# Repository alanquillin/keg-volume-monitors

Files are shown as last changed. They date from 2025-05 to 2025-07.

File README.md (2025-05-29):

# DIY Keg Volume Monitors

While there are many commercially available monitors for kegs out there, this project is designed for the DIY/tinkerer at heart and aimed to be a more cost effective way to add volume monitors to your kegs.  The core of these monitors is the particle.io Photon 2 micro-controller.  This low cost micro-controller adds Wifi and BluetoothLE support as well and integrated cloud.  This allows the keg monitor service to get stats and execute functions against the devices even when they are not on the same network. The particle.io cloud is free (for up to 100 devices) so it makes it perfect for this type of DIY project.  While there are cheaper micro-controllers out there, the Photon 2 was chosen because its extra features were worth the extra few dollars.

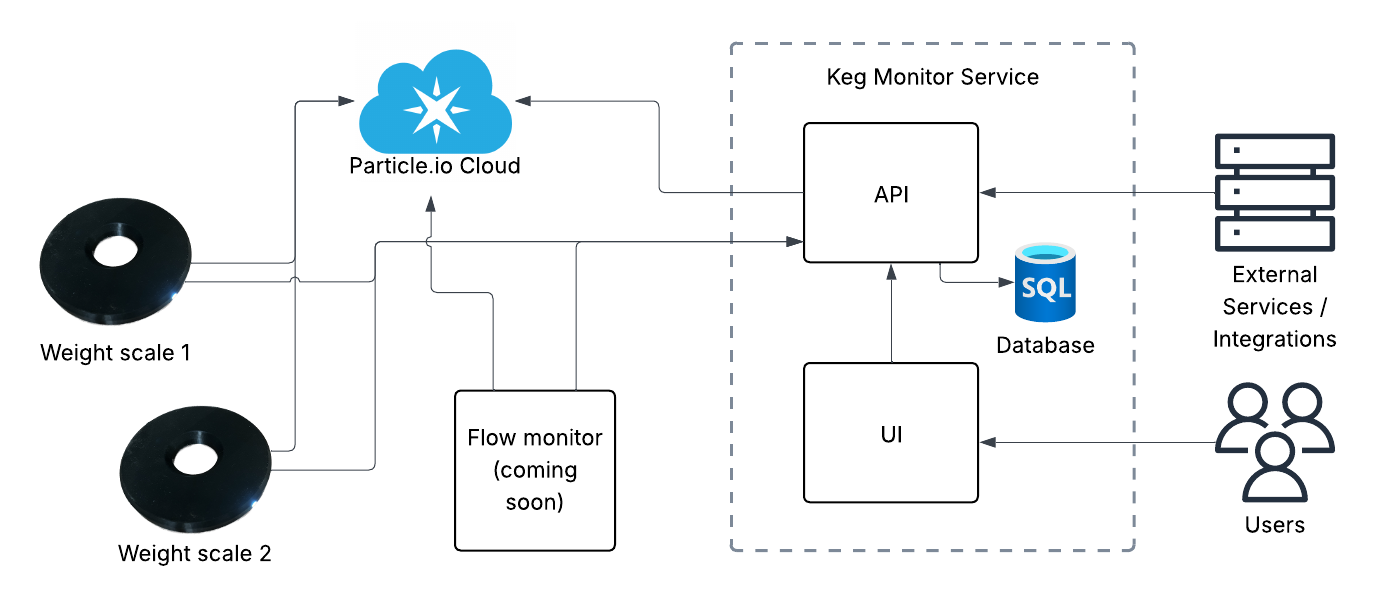
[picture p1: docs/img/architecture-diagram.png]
Weight scale monitor pic


## Monitors

- [Weight Scale](./monitors/weight/README.md): Monitors the volume of the keg based on the current weight.
- Flow Monitor _(coming soon)_: Monitors the remaining volume in the keg bacged on how much liquid flowed through the sensors.

## The web service

The core of all of this is the web service.  This offers an API, both for the devices to post too, as well as external services to integrate with.  There is also a light weight UI for viewing the status of and managing the devices.  The service also proxies the calls to particle cloud to execute certain functions on the different devices.

## Whats next?

See our [issues page](https://github.com/alanquillin/keg-volume-monitors/issues) for upcoming milestones and changes on our roadmap.

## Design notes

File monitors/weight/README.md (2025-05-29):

# Weight Based Keg Volume Monitor

Inspired by the now discontinued Plaato keg, this monitor uses the weight of the keg over time to determine the current
 volume based on the weight of the empty keg and the weight of a full keg.  I love the Plaato keg, and was sad when they
 announced their pivot away from home brewing gear and would no longer be selling, innovating or supporting the Plaato
 keg.  In my search I found a few other DIY clones using low cost hardware and existing technologies.  However, I wanted
 to build some truly DIY with fully opensource software.  So I designed my own keg scale using the Particle Photon 2 platform.

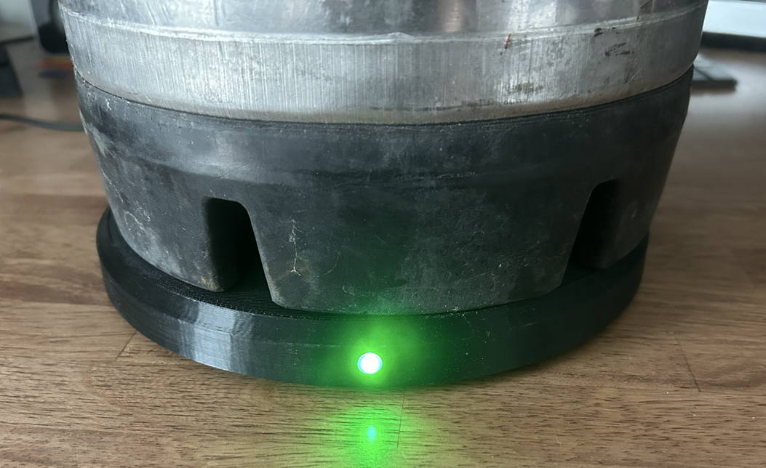
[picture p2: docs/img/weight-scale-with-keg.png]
Weight scale monitor pic

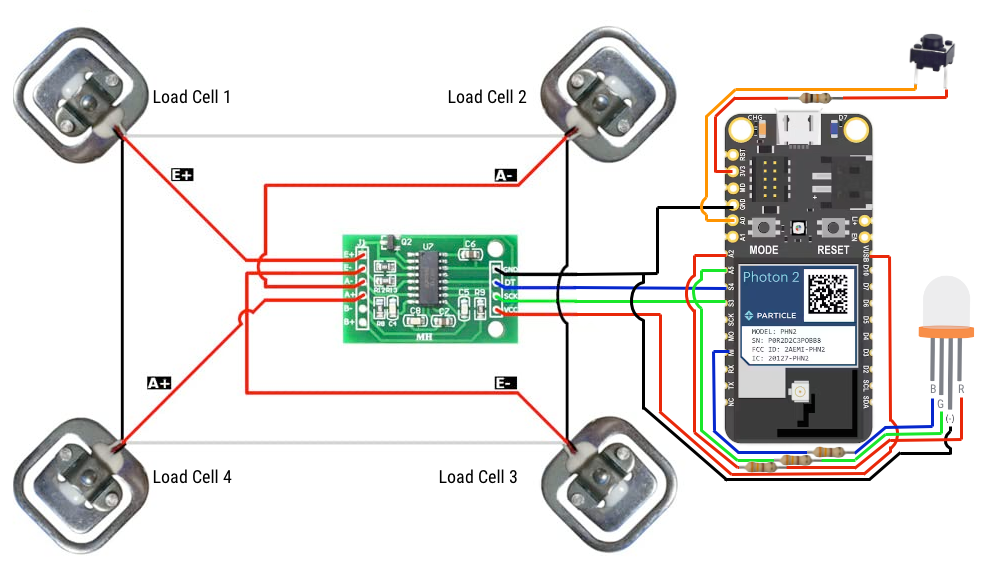
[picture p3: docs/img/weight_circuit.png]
Weight scale monitor - load cell circuit diagram


## Parts required

- [Particle Photon2](https://store.particle.io/products/photon-2) (optionally will work with discontinued Photon or Argon)
- [4 Load Cells w/ HX711 amplifier](https://www.amazon.com/Bridge-Digital-Amplifier-Arduino-DIYmalls/dp/B086ZHXNJH)
- [5mm RGB Led (common cathode)](https://www.amazon.com/PATIKIL-Emitting-Mounting-Bracket-Transparent/)
- 3X 330 ohm Resistor
- [5mm LED holder](https://www.amazon.com/PATIKIL-Emitting-Mounting-Bracket-Transparent/dp/B0C54Y99NQ)

### Optional components

- Micro USB cable (is using the optinal riser boards below, I would recommend a cable with extremely slim connectors
like [these](https://www.amazon.com/dp/B09XKYP32W).  The .stl files for the case add additional room for the cables, but its better to be safe than sorry ;P)
- [6mmX6mm single pole push button switch](https://www.amazon.com/dp/B07WF76VHT)
- 10k Ohm resistor

#### Optional Parts for custom riser boards

I have added the [EAGLE files](./eagle) to manufacture helper riser boards simplify and cleanup the internal wiring.  Please [contact me](mailto:alanquillin@gmail.com) for more information. 

- JST-PH connectors
  - 4 pole connectors
    - 3 X [S4B-PH-K-S](https://www.digikey.com/en/products/detail/jst-sales-america-inc/S4B-PH-K-S/926628) right angle female through hole solder connectors
    - 1 X [B4B-PH-K-S](https://www.digikey.com/en/products/detail/jst-sales-america-inc/B4B-PH-K-S/926613) straight female through hole solder connector
    - 8 X [PHR-4](https://www.digikey.com/en/products/detail/jst-sales-america-inc/PHR-4/608606) male connectors
  - 3 pole
    - 4 X [S3B-PH-K-S](https://www.digikey.com/en/products/detail/jst-sales-america-inc/S3B-PH-K-S/926627) female through hole solder connectors
    - 8 X [PHR-3](https://www.digikey.com/en/products/detail/jst-sales-america-inc/PHR-3/527357) male connectors
  - 2 pole
    - 2 X [S2B-PH-K-S](https://www.digikey.com/en/products/detail/jst-sales-america-inc/S2B-PH-K-S/926626) female through hole solder connectors
    - 4 X [PHR-2](https://www.digikey.com/en/products/detail/jst-sales-america-inc/PHR-2/608607) male connectors
  - 20 X [SPH-004](https://www.digikey.com/en/products/detail/jst-sales-america-inc/SPH-004T-P0-5S/608759) crimp terminal pins
- [2m X 6MM self taping screws](https://www.amazon.com/dp/B01KXS7TOI).  The STLs do not have pre-drilled holed for the screws to hold the circuit boards, and thats because the risers are not perfect ;P, so self taping screws will allow you to screw right into the solid plastic.

## Links

- [Another DIY Plaato Keg clone](https://www.youtube.com/watch?v=QF1B8yD9jy4) from the [Trouble Brewing](https://www.youtube.com/@TroubleBrewing)
YouTube channel.  This one uses a NodeMCU 8266 module and Home Assistant Server.  However, I am not a huge fan of these modules or Home Assistant
and I wanted to build something with fully opensource software.
- [Wiring up and calibrating HX711 with 4 load cell using arduino](https://www.youtube.com/watch?v=LIuf2egMioA)

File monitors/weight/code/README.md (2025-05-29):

# Weight Based Keg Volume Monitor: Controller Firmware

## Setting up wifi

To initiate or update the WiFi for a given device, make sure to add your wifi redencials to the local `wifi-creds.json`.  

``` json
{
    "network": "MYSSID",
    "security": "WPA2_PSK",
    "password": "MYWIFIPASS",
    "hidden": false
}
```

for more details see the [documentation](https://docs.particle.io/reference/developer-tools/cli/).

Then update the device with following command

``` shell
make initi-wifi
```

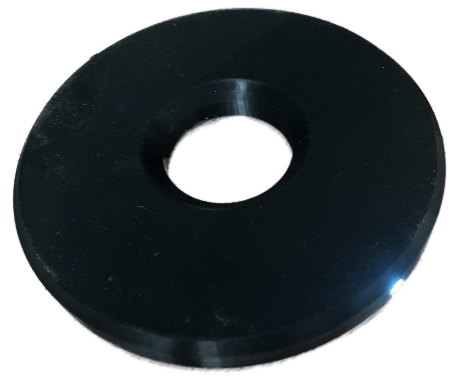
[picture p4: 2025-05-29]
docs/img/weight-scale-transparent.png

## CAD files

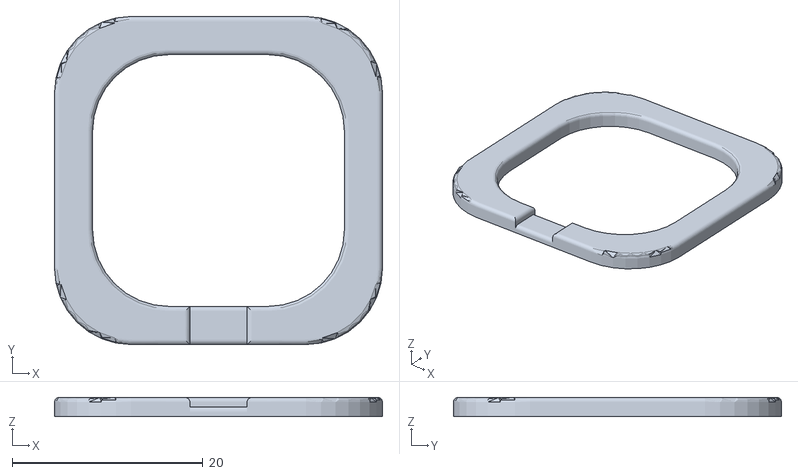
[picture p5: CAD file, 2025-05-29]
monitors/weight/stl/Keg Weight Monitor - Load Cell Mount Top Bevel.stl
34.4 x 34.4 x 2.00

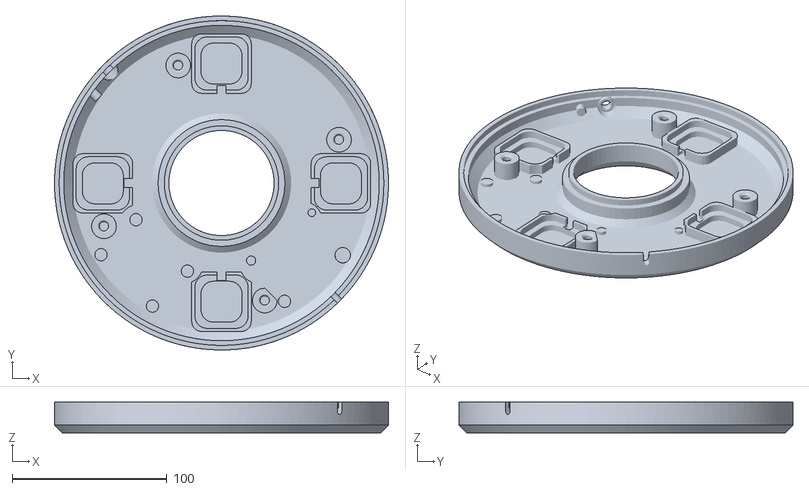
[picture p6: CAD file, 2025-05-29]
monitors/weight/stl/Keg Weight Monitor - Top.stl
216.0 x 216.0 x 20.0

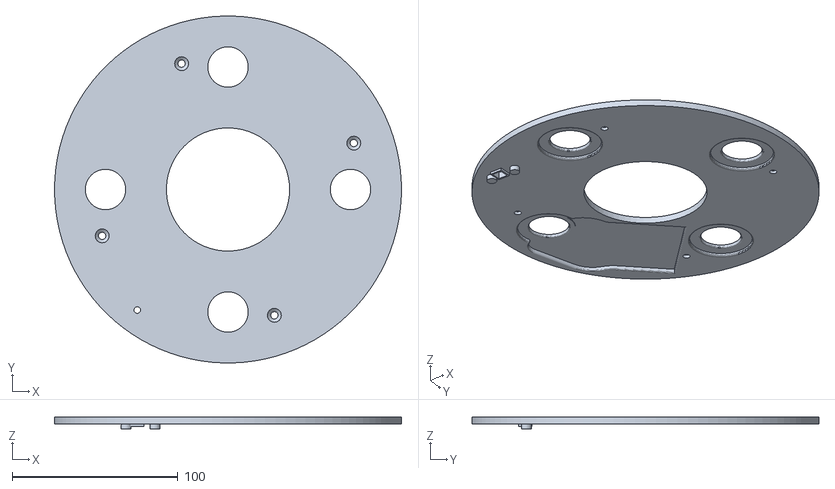
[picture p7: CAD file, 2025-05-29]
monitors/weight/stl/Keg Weight Monitor - Bottom.stl
209.6 x 209.5 x 7.00

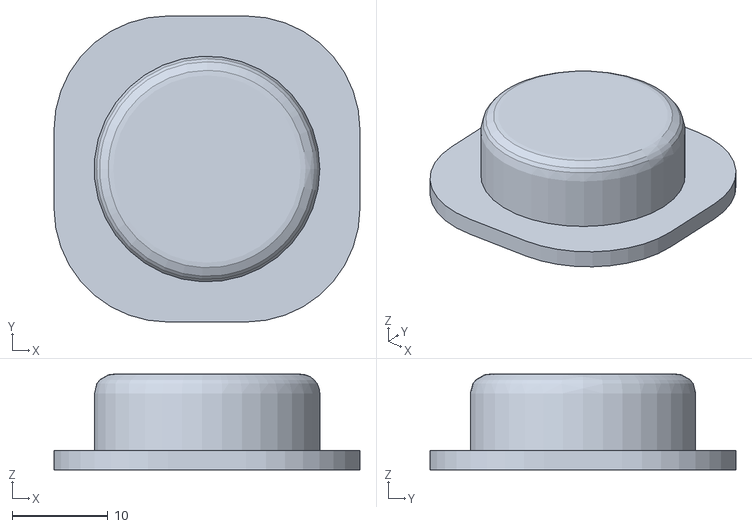
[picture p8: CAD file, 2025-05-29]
monitors/weight/stl/Keg Weight Monitor - Feet.stl
32.0 x 32.0 x 10.0

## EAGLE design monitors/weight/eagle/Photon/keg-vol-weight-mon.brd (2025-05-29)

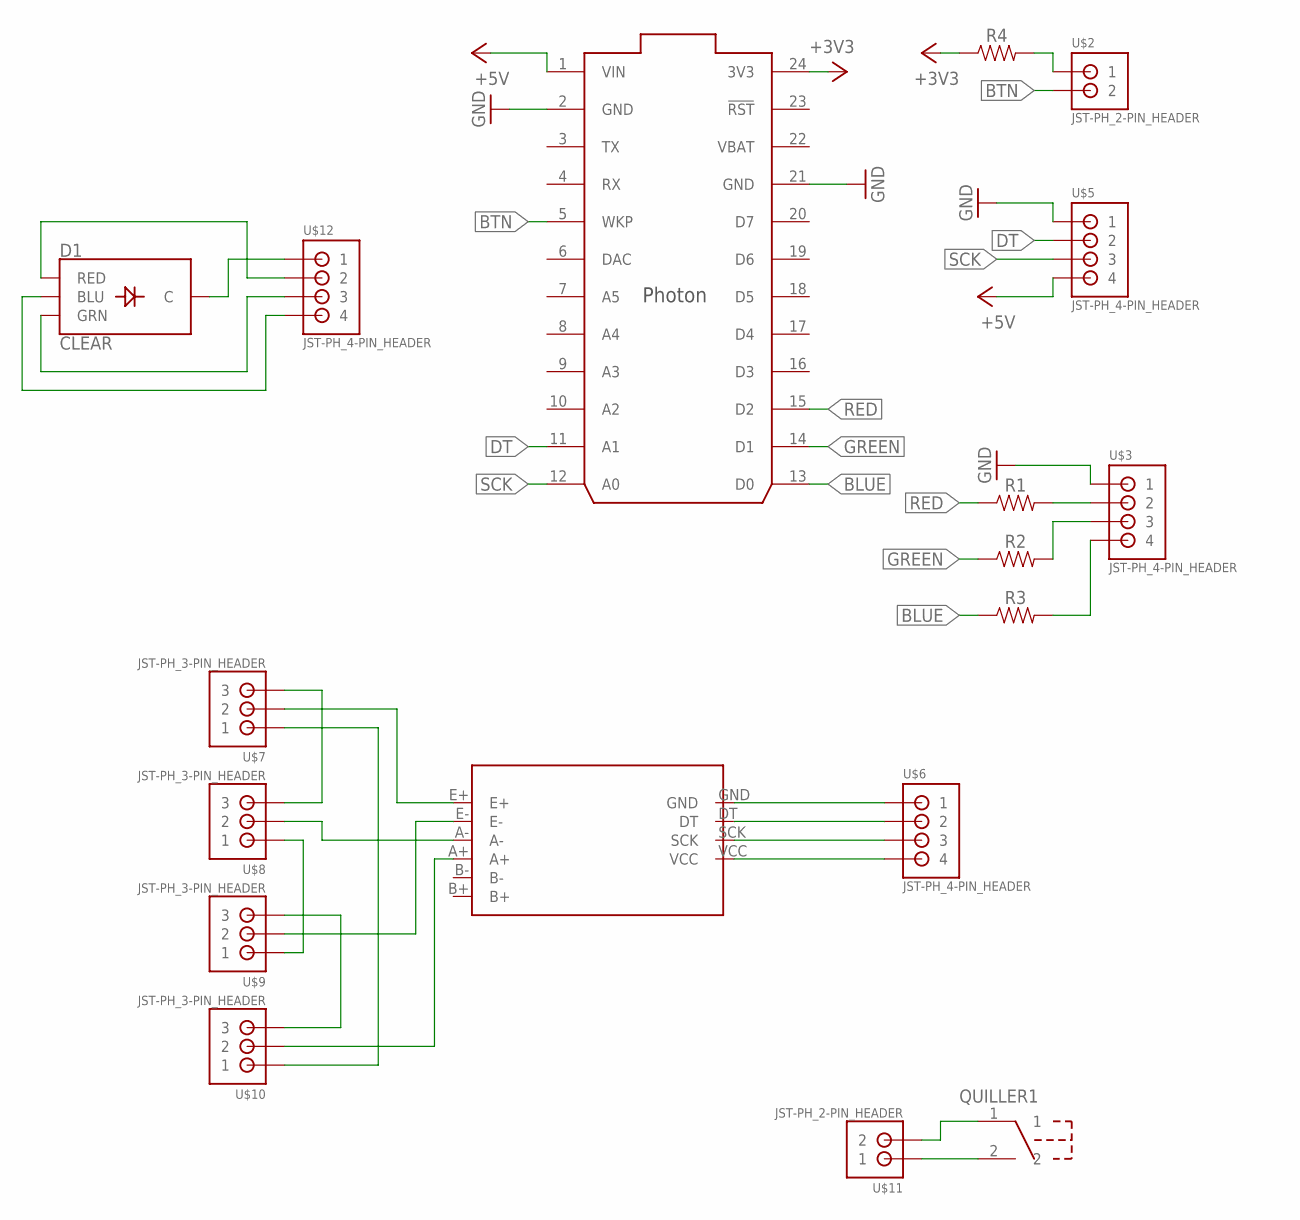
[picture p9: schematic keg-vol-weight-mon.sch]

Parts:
D1: CLEAR; LED-RGB-THRU
QUILLER1: 6MM-2PIN-TAC-MOM-SWITCH
R1, R2, R3, R4: AXIAL-0.3
U$1: PHOTON_WITH_HEADERS; PHOTON
U$2, U$11: JST-PH_2-PIN_HEADER; JST_B2B-PH_HEADER
U$3, U$5, U$6, U$12: JST-PH_4-PIN_HEADER; JST_B4B-PH_HEADER
U$4: HX711
U$7, U$8, U$9, U$10: JST-PH_3-PIN_HEADER; JST_B3B-PH_HEADER

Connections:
+3V3: R4.P$1 (1), U$1.24 (3V3)
+5V: U$1.1 (VIN), U$5.P4 (4)
BLUE: R3.P$1 (1), U$1.13 (D0)
BTN: U$1.5 (WKP), U$2.P2 (2)
DT: U$1.11 (A1), U$5.P2 (2)
GND: U$1.2 (GND), U$1.21 (GND), U$3.P1 (1), U$5.P1 (1)
GREEN: R2.P$1 (1), U$1.14 (D1)
unnamed: R2.P$2 (2), U$3.P3 (3)
unnamed: R3.P$2 (2), U$3.P4 (4)
unnamed: R4.P$2 (2), U$2.P1 (1)
unnamed: U$4.E+, U$7.P2 (2)
unnamed: R1.P$2 (2), U$3.P2 (2)
unnamed: U$4.A-, U$8.P2 (2)
unnamed: U$4.E-, U$9.P2 (2)
unnamed: U$4.A+, U$10.P2 (2)
unnamed: U$7.P3 (3), U$8.P3 (3)
unnamed: U$8.P1 (1), U$9.P1 (1)
unnamed: U$9.P3 (3), U$10.P3 (3)
unnamed: U$7.P1 (1), U$10.P1 (1)
unnamed: U$4.GND, U$6.P1 (1)
unnamed: U$4.DT, U$6.P2 (2)
unnamed: U$4.SCK, U$6.P3 (3)
unnamed: U$4.VCC, U$6.P4 (4)
unnamed: QUILLER1.1, U$11.P2 (2)
unnamed: QUILLER1.2, U$11.P1 (1)
unnamed: D1.2 (C), U$12.P1 (1)
unnamed: D1.4 (BLU), U$12.P4 (4)
unnamed: D1.3 (GRN), U$12.P3 (3)
unnamed: D1.1 (RED), U$12.P2 (2)
RED: R1.P$1 (1), U$1.15 (D2)
SCK: U$1.12 (A0), U$5.P3 (3)
VBAT: U$1.22 (VBAT)

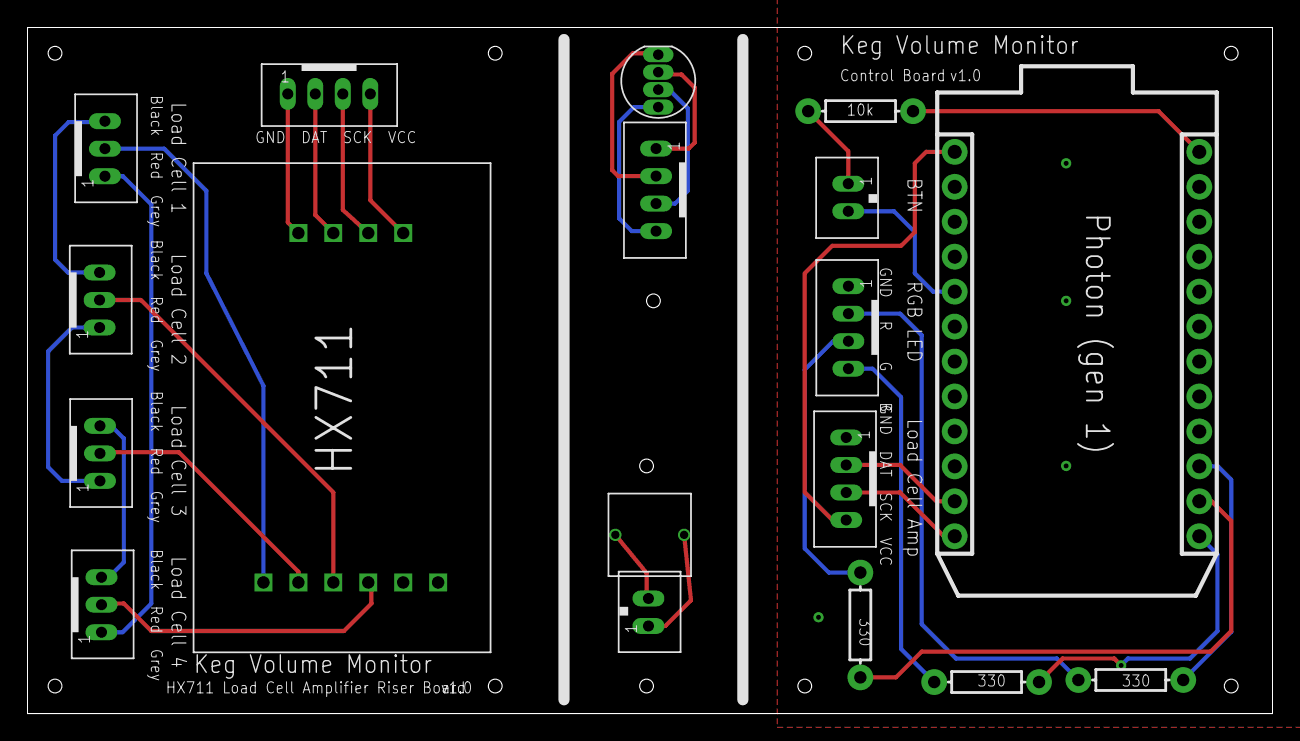
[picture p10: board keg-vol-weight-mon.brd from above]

Board: 2 copper layers, 90.5 x 49.9 mm, 18 parts (0 on the bottom side), 31 nets.

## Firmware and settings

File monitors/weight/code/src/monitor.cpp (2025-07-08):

#include "Particle.h"
#include "env.h"
#include "config.h"
#include <HX711ADC.h>
#include <math.h>
//#include "../../../shared-lib/rgb_led.h"
#include "rgb_led.h"
//#include "../../../shared-lib/service.h"
#include "service.h"

SYSTEM_MODE(SEMI_AUTOMATIC);
// Run Setup code immediately.  This is enabled by default in OS v6.2.0 and above
#if (SYSTEM_VERSION < SYSTEM_VERSION_DEFAULT(6, 2, 0))
SYSTEM_THREAD(ENABLED);
#endif

// declare function prototypes
bool sendStatus();
bool getSetDeviceData();

Timer statusUpdater(STATUS_UPDATE_PERIOD_MS, sendStatus);

SerialLogHandler logHandler(LOG_LEVEL_WARN, {
    { "app", LOG_LEVEL_TRACE }, // Default logging level for all app messages
    { "app.service", LOG_LEVEL_TRACE } // Logging level for data service
});

HX711ADC scale(HX711_DOUT_PIN, HX711_SCK_PIN);		// parameter "gain" is omitted; the default value 128 is used by the library
RGBLED led(RED_PIN, GREEN_PIN, BLUE_PIN);
DataService dataService(SERVICE_ENABLED, "weight", HOSTNAME, PORT, API_KEY, false);
device_data_t deviceData = {true};

float EMPTY_KEG_W = DEFAULT_EMPTY_KEG_W;
float LAST_MEASUREMENT = 0;
time32_t LAST_MEASUREMENT_TS = 0;

bool BTN_PRESSED = false;
unsigned long BTN_PRESSED_ON;
bool CALIBRATION_MODE_ENABLED = false;
bool CALIBRATING = false;
bool TESTING_LEDS = false;
bool MAINTENANCE_MODE = false;

int _getState(bool doPing) {
    if (CALIBRATING) {
        return 11;
    }

    if (CALIBRATION_MODE_ENABLED) {
        return 10;
    }

    if (MAINTENANCE_MODE) {
        return 99;
    }

    if (doPing) {
        if (!dataService.ping()) {
            return 2;
        }
    }

    return 1;
}

void storeCalibrationScale(float cal) {
    EEPROM.put(0, cal);
}

float getCalibrationScale() {
    float cal;
    EEPROM.get(0, cal);
    return cal;
}

void storeCalibrationOffset(long offset) {
    EEPROM.put(4, offset);
}

long getCalibrationOffset() {
    long offset;
    EEPROM.get(4, offset);
    return offset;
}

void storeEmptyKegWeight(float val) {
    EEPROM.put(8, val);
}

float getEmptyKegWeight() {
    float val;
    EEPROM.get(8, val);
    return val;
}

bool sendStatus() {
    if (deviceData.isNull) {
        Log.trace("No device info currently set, attempting to retrieve before sending status");
        if(!getSetDeviceData()){
            Log.warn("No device info found from service.  Service may not be available ATM, skipping sendStatus.");
            return false;
        }
    }

    device_status_t status;
    status.id = deviceData.id;
    status.latestMeasurement = LAST_MEASUREMENT;
    status.latestMeasurementTS = LAST_MEASUREMENT_TS;
    status.emptyKegWeight = EMPTY_KEG_W;
    
    status.state = _getState(false);
    return dataService.sendStatus(status);
}

void tare() {
    scale.power_up();
    scale.tare();
    scale.power_down();
    storeCalibrationOffset(scale.get_offset());
    Log.trace("Tare complete, offset stored: %li", scale.get_offset());
}

void initCalibration() {
    CALIBRATION_MODE_ENABLED = true;

    scale.set_scale();
    tare();
}

// Puts the scale in calibration mode and resets.  Assumes the scale is clear or has the inital tare weight on
/**
 * @brief CLOUD FUNCTION CALLBACK - Performs a tare function and stores the offset in memory
 * 
 * @param _ String: ignored and unused
 * @return int 
 */
int tareCld(String _ = "") {
    tare();
    return 1;
}

/**
 * @brief CLOUD FUNCTION CALLBACK - Performs a tare function, resets the calibration scale and puts the device in calibration mode
 * 
 * @param _ String: ignored and unused
 * @return int 
 *      @error codes:
 *          -99 - Function succeeded but was unable to send the status update to the service
 */
int initCalibrationCld(String _ = "") {
    initCalibration();
    
    if (!sendStatus()) {
        return -99;
    }
    return 1;
}

/**
 * @brief CLOUD FUNCTION CALLBACK - Cancels calibration mode and resets the previous calibration scale value
 * 
 * @param _ String: ignored and unused
 * @return int - A value of 1 is return to represent successfully cancellation of calibration mode
 *      @error codes:
 *          -1 - If the device is currently calibration
 *          -2 - If there is no previous calibration value found.
 *          -99 - Function succeeded but was unable to send the status update to the service
 */
int cancelCalibrationCld(String _ = "") {
    if (CALIBRATING) {
        return -1;
    }
    float cal = getCalibrationScale();
    float offset = getCalibrationOffset();
    
    if (isnan(cal) || isnan(offset)) {
        return -2;
    }
    
    //blinkLEDSlow.stop();
    scale.set_scale(cal);
    scale.set_offset(offset);
    
    CALIBRATION_MODE_ENABLED = false;
    if(!sendStatus()) {
        return -99;
    }
    return 1;
}

/**
 * @brief CLOUD FUNCTION CALLBACK - Resets the local EEPROM and restarts the system.
 * 
 * @param _ String: ignored and unused
 * @return int 
 */

int cleanMemAndRestartCld(String _ = "") {
  EEPROM.clear();
  System.reset(2);
  return 1;
}

/**
 * @brief CLOUD FUNCTION CALLBACK - Uses the provided known weight to calibrate the scale.  The weight unit is irrelevant 
 * and whatever weight you used will be used to provide wights with the same units.
 * 
 * Example:  You passed in the value of 4535.923 which represented the weight in gram, then the scale will provide units
 *           in grams.  So to get lbs, you would divide the value provided by the scale by 453.592.  
 * 
 * @param String:cal_weight_str - The string representing the known weight to use for calibration
 * @return int - A value of 1 is return to represent successful calibration, negative numbers return indicate an error
 *      @error codes:
 *          -1 - Unable to parse input value to float
 *          -2 - Invalid input value.  Cannot be lower that the default empty keg weight
 *          -3 - Calibration failed
 *          -99 - Function succeeded but was unable to send the status update to the service
 * 
 * 
 * TODO: 
 *      - Need to make this smarter and compare the sample iterations to try and identify if the weight have either
 *        been removed or changed while calibration was in progress
 */
 
int calibrateCld(String calWeight_s) {
    float calWeight = calWeight_s.toFloat();
    if (calWeight == 0 && calWeight_s != "0") {
        return -1;
    }

    if (calWeight < EMPTY_KEG_W) {
        if (!ALLOW_LOW_WEIGHT_CALIBRATION) {
            Log.error("Calibration failed because the calibration weight was below %.2fg", EMPTY_KEG_W);
            return -2;
        }

        Log.warn("Calibrating with weight lower %.2fg which is less than the empty keg weight: %.2f", calWeight, EMPTY_KEG_W);
    }
    
    CALIBRATING = true;
    sendStatus();
    Log.info("Starting calibration.  Known calibration weight: %0.2f", calWeight);
    float units_t = 0;
    int cnt = 10;
    int sampleCnt = 10;
    scale.power_up();
    Log.trace("starting calibration sampling.  Total sample groups: %i", cnt);
    for(int i=0; i<cnt; i++) {
        float units = scale.get_units(sampleCnt);
        units_t = units_t + units;
        Log.trace("Sample group %i of %i.  Sample count = %i, average unit value: %.2f", i+1, cnt, sampleCnt, units);
        delay(500);
    }
    float cal = (units_t / cnt) / calWeight;
    Log.info("Calibration complete, calibration scale value: %0.2f", cal);
    scale.set_scale(cal);

    Log.trace("Testing calibration.  New sampple must be withing the differential threshold: %.2f", DIFF_THRESHOLD);
    float diff = calWeight * DIFF_THRESHOLD;
    float max = calWeight + diff;
    float min = calWeight - diff;
    float sample = scale.get_units(sampleCnt);
    
    boolean validated=false;
    if(sample < min || sample > max) {
        validated = false;
        Log.error("Calibration failed, the new sample %.2f was out side of the allowed range: min: %.2f, max: %.2f", sample, min, max);
        scale.set_scale();  // reset calibration scale
    } else {
        Log.trace("Calibration validation succeeded!");
        validated = true;
        storeCalibrationScale(cal);
    }

    scale.power_down();
    CALIBRATION_MODE_ENABLED = false;
    CALIBRATING = false;
    if(!sendStatus() && validated){
        return -99;
    }
    if (!validated) {
        return -3;
    }
    return 1;
}

/**
 * @brief CLOUD FUNCTION CALLBACK - Runs a quick visual test of the RGB LED.  The LED will cycle once from 
 *      White->Red->Green->Blue for 2 seconds each.  
 * 
 * @param _ String: ignored and unused
 * @return int 
 */
int testLedsCld(String _ = "") {
    if (CALIBRATING || CALIBRATION_MODE_ENABLED) {
        Log.error("Cannot run LED test as calibration is in process.");
        return -1;
    }
    
    TESTING_LEDS = true;
    
    Log.info("Starting LED testing.");
    Log.info("Testing white");
    led.setColor(RGB_WHITE, false);
    delay(2000);
    Log.info("Testing red");
    led.setColor(RGB_RED, false);
    delay(2000);
    Log.info("Testing green");
    led.setColor(RGB_GREEN, false);
    delay(2000);
    Log.info("Testing blue");
    led.setColor(RGB_BLUE, false);
    delay(2000);
    Log.info("LED test complete");
    led.setColor(led.getCurrentColor());
    
    TESTING_LEDS = false;
    
    return 1;
}

/**
 * @brief CLOUD FUNCTION CALLBACK - Sends the current device status to service
 * 
 * @param _ String: ignored and unused
 * @return int A value of 1 is return to represent successful data push
 *      @error codes:
 *          -1 - Failed to push the data to the data service
 *          -2 - The extended device information could not be retrieved from the data service
 *          -3 - No sample has been taken yet
 */
int sendStatusCld(String _ = "") {
    if (deviceData.isNull) {
        Log.info("Extended device data not found from data service, attempting to discover...");
        deviceData = dataService.findDevice();

        if (deviceData.isNull) {
            Log.error("discovery failed, no extended device data could be retrieved form the data service");
            return -2;
        }
    }

    if (LAST_MEASUREMENT_TS == 0) {
        return -3;
    }
    
    if (sendStatus()) {
        Log.info("Successfully saved the measurement with the Data Service");
        return 1;
    } else {
        Log.error("Failed to save the measurement with the Data Service");
        return -1;
    }
}
/**
 * @brief CLOUD FUNCTION CALLBACK - Puts device in maintenance mode
 * 
 * @param _ String: ignored and unused
 * @return int 
 *          -99 - Function succeeded but was unable to send the status update to the service
 */
int startMaintenanceModeCld(String _ = "") {
    Log.info("Entering maintenance mode.");
    MAINTENANCE_MODE = true;
    if (!CALIBRATING) {
        if(!sendStatus()){
            return -99;
        }
    }
    return 1;
}

/**
 * @brief CLOUD FUNCTION CALLBACK - Exits maintenance mode
 * 
 * @param _ String: ignored and unused
 * @return int 
 *          -99 - Function succeeded but was unable to send the status update to the service
 */
int stopMaintenanceModeCld(String _ = "") {
    Log.info("Exiting maintenance mode.");
    MAINTENANCE_MODE = false;
    if (!CALIBRATING) {
        if(!sendStatus()){
            return -99;
        }
    }
    return 1;
}

/**
 * @brief CLOUD FUNCTION CALLBACK - Sends the last stored sample to the data service
 * 
 * @param _ String: ignored and unused
 * @return int Value representing this current state of the device
 *          1 - Normal function and data service available
 *          2 - Normal function but data service is not available
 *          10 - Calibration mode enabled
 *          11 - Calibration in progress
 *          99 - Maintenance mode
 */
int getStateCld(String _ = "") {
    return _getState(true);
}

/**
 * @brief CLOUD FUNCTION CALLBACK - Set the empty keg weight
 * 
 * @param String:emptyKegWeight_s - The string representing the empty keg weight
 * @return int A value of 1 is return to represent successful data push
 *          -1 - Unable to parse input value to float
 */
int setEmptyKegWeightCld(String emptyKegWeight_s = "") {
    float emptyKegWeight = emptyKegWeight_s.toFloat();
    if (emptyKegWeight == 0 && emptyKegWeight_s != "0") {
        return -1;
    }

    EMPTY_KEG_W = emptyKegWeight;
    storeEmptyKegWeight(emptyKegWeight);

    return 1;
}

bool getSetDeviceData() {
    bool res = dataService.ping();
    if (!res) {
        Log.error("Data service ping failed.");
        return false;
    } else {
        Log.info("Data service ping successful");
        deviceData = dataService.findDevice();
        if (deviceData.isNull) {
            Log.error("Device not found with Data Service.");
            deviceData = dataService.registerDevice();
            if (deviceData.isNull) {
                Log.error("Failed to register device with the Data Service");
                return false;
            }
        } else {
            Log.trace("Found or successfully registered device with the Data Service.  Id: %s", deviceData.id.c_str());
        }
    }
    return true;
}

void setup() {
    led.begin();
    led.setColor(RGB_WHITE);
    led.blinkFast();
    
    pinMode(BTN_PIN, INPUT_PULLDOWN);
    
    waitFor(Serial.isConnected, 10000);
    
    Log.info("Initiating startup sequence...");
    Log.trace("Attempting to connect to WiFi.");

    WiFi.on();
    WiFi.connect();
    
    if(waitFor(WiFi.ready, 10000)){
        Log.info("Successfully connected to WiFi.");
    } else {
        Log.error("Failed to connect to Wifi in time... this may go badly");
#if (PLATFORM_ID == PLATFORM_PHOTON || PLATFORM_ID == PLATFORM_PHOTON_PRODUCTION)
        Log.info("Putting device WiFi in listening mode.");
        WiFi.listen();
#endif
    }

    scale.begin();
    scale.power_down();
    
    Particle.function("startCalibration", initCalibrationCld);
    Particle.function("cancelCalibration", cancelCalibrationCld);
    Particle.function("calibrate", calibrateCld);
    Particle.function("tare", tareCld);
    Particle.function("testLEDs", testLedsCld);
    Particle.function("clearMemory", cleanMemAndRestartCld);
    Particle.function("sendStatus", sendStatusCld);
    Particle.function("startMaintenanceMode", startMaintenanceModeCld);
    Particle.function("stopMaintenanceMode", stopMaintenanceModeCld);
    Particle.function("getState", getStateCld);
    Particle.function("setEmptyKegWeight", setEmptyKegWeightCld);
    
    Log.trace("Connecting to Particle Cloud");
    Particle.connect();
    if(waitFor(Particle.connected, 10000)) {
        Log.info("Successfully connected to Particle cloud");
    } else {
        Log.error("Failed to connect to Particle cloud");
    }

    getSetDeviceData();

    if (deviceData.isNull) {
        Log.trace("No deivice data found from service, checking EEPROM for empty keg weight");
        float emptyKegWeight = getEmptyKegWeight();
        if (!isnan(emptyKegWeight) && emptyKegWeight > 0.0) {
            Log.trace("Retrieved empty keg weight from EEPROM: %.2f", emptyKegWeight);
            EMPTY_KEG_W = emptyKegWeight;
        } else {
            Log.warn("No empty keg weight found in EEPROM.  Falling back to default: %.2f", EMPTY_KEG_W);
        }
    } else {
        Log.trace("Retrieved empty keg weight in device data from service: %.2f", deviceData.emptyKegWeight);
        EMPTY_KEG_W = deviceData.emptyKegWeight;
        storeEmptyKegWeight(EMPTY_KEG_W);
    }

    float cal = getCalibrationScale();
    long calOffset = getCalibrationOffset();
    Log.trace("Startup Calibration Value: %.2f, offset: %li", cal, calOffset);
    
    if (isnan(cal) || cal == 0.0 || isnan(calOffset) || calOffset == 0) {
        Log.info("No calibration set in memory, starting calibration mode.");
        initCalibration();	
    } else {
        scale.set_scale(cal);
        scale.set_offset(calOffset);
    }

    statusUpdater.start();
    sendStatus();
    led.stopBlink();

    Log.trace("Scale config: offset: %li, scale: %.2f", scale.get_offset(), scale.get_scale());
    Log.trace("Startup sequence complete!");
}

void loop() {
    int dVal = digitalRead(BTN_PIN);
    if (dVal == HIGH) {
        if (!BTN_PRESSED) {
            Log.info("External function switch press detected");
            BTN_PRESSED_ON = millis();
        }
        BTN_PRESSED = true;
    }

    if (BTN_PRESSED) {
        led.setColor(RGB_RED);
        unsigned long now = millis();
        unsigned long pressDuration = now - BTN_PRESSED_ON;
        bool doResetAction = false;
        if (pressDuration >= 5000) {
            led.blinkFast();
            doResetAction = true;
        }
        if (dVal != HIGH) {
            BTN_PRESSED = false;
            Log.info("External function switch pressed for %.2f seconds", pressDuration / 1000.0);
            if (doResetAction) {
                Log.info("Reset initiated by external function switch.");
                led.blinkSlow();
                delay(3000);
                System.reset(1);
            } 
        } else {
            delay(500);
        }
    } else if (TESTING_LEDS) {
        led.stopBlink();
        delay(1000);
    } else if (CALIBRATING) {
        led.setColor(RGB_BLUE);
        led.blinkFast();
        delay(500);
    } else if (CALIBRATION_MODE_ENABLED) {
        led.setColor(RGB_BLUE);
        led.blinkSlow();
        delay(1000);
    } else if (MAINTENANCE_MODE) {
        led.stopBlink();
        led.setColor(RGB_ORANGE);

        delay(1000);
    } else {
        led.stopBlink();
        // if moving from a different state, assume an empty keg and set to white.  
        if (led.getCurrentColor() != RGB_COLOR_WHITE && led.getCurrentColor() != RGB_COLOR_GREEN) {
            led.setColor(RGB_WHITE);
        }

        scale.power_up();
        float units = scale.get_units(10);
        scale.power_down(); // put the ADC in sleep mode
        
        // The sampling can take a second or 2, and in the mean time, cloud fucntions can change the state, this checks that before doing anything with the value.
        if (!BTN_PRESSED && !TESTING_LEDS && !CALIBRATING && !CALIBRATION_MODE_ENABLED && !MAINTENANCE_MODE) {
            Log.trace("Sample taken: %.2f", units);
                
            if (units < EMPTY_KEG_W && LAST_MEASUREMENT < EMPTY_KEG_W) {
                led.setColor(RGB_WHITE);
            } else {
                led.setColor(RGB_GREEN);
                float diff = units * DIFF_THRESHOLD;
                if (units > (LAST_MEASUREMENT + diff) || units < (LAST_MEASUREMENT - diff)) {
                    Log.info("New measurement found that exceeds the differential threshold.  Measurement value: %.2f", units);
                    Log.trace("Last measurement: %.2f, current measurements: %.2f, differential: %.2f, differential threshold: %.2f", LAST_MEASUREMENT, units, diff, DIFF_THRESHOLD);

                    LAST_MEASUREMENT = units;
                    LAST_MEASUREMENT_TS = Time.now();

                    if (deviceData.isNull) {
                        Log.info("Extended device data not found from data service, attempting to discover");
                        deviceData = dataService.findDevice();
                    }

                    if (deviceData.isNull) {
                        Log.warn("UNKNOWN id for the device from the device service...");
                    } else {
                        led.blinkFast();
                        if (dataService.sendMeasurement(deviceData.id, units, LAST_MEASUREMENT_TS)) {
                            Log.info("Successfully saved the measurement with the Data Service");
                        } else {
                            Log.error("Failed to save the measurement with the Data Service");
                        }
                        led.stopBlink();
                    }
                }
            }
        }

        delay(1000);
    }
  
}

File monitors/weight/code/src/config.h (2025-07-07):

#ifndef _KEG_VOL_MON_WEIGHT_CONFIG_
#define _KEG_VOL_MON_WEIGHT_CONFIG_

#include "env.h"
#include "Particle.h"

#if (PLATFORM_ID == PLATFORM_PHOTON || PLATFORM_ID == PLATFORM_PHOTON_PRODUCTION)
    /*******************************
    Photon - prototype
    *******************************/
    // const int HX711_DOUT_PIN = D5;
    // const int HX711_SCK_PIN = D4;
    // const int BTN_PIN = D6;
    // const int RED_PIN = D3;
    // const int GREEN_PIN = D2;
    // const int BLUE_PIN = D1;

    const int HX711_DOUT_PIN = A1;
    const int HX711_SCK_PIN = A0;
    const int BTN_PIN = A7;
    const int RED_PIN = D2;
    const int GREEN_PIN = D1;
    const int BLUE_PIN = D0;

    const String CHIP_MODEL = "Photon";
#endif

#if (PLATFORM_ID == PLATFORM_P2)
    const int HX711_DOUT_PIN = D19;
    const int HX711_SCK_PIN = D18;
    const int BTN_PIN = A0;
    const int RED_PIN = D13;
    const int GREEN_PIN = D14;  
    const int BLUE_PIN = D16;

    const String CHIP_MODEL = "Photon2 / P2";
#endif

// FOR HOSTNAME, API_KEY and PORT, check the env.h file.
const bool SERVICE_ENABLED = true;

const float DIFF_THRESHOLD = .01;

/** Most standard stainless steal corny keg are a little over 4 Kg.  
 * Most standard stainless steal corny keg are a little over 4 Kg.  
 * This assumes calibration was done in g, if another unit was used then
 * Update this to the min weight you want as your threshold */ 
const float DEFAULT_EMPTY_KEG_W = 4000.0;
/** if false, calibration will fail if the calibration weight provided is 
 * less than DEFAULT_EMPTY_KEG_W */ 
const bool ALLOW_LOW_WEIGHT_CALIBRATION = true;

const int STATUS_UPDATE_PERIOD_MS = 600000;
const int WIFI_MON_PERIOD_MS = 120000;

#endif

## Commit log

2025-05-29 Initial commit (#1)
    * initial commit with wieght sensor
    * Updated REDMEs
    * added initial shell for the server
    * added basic Device and Measurements CRUD API
    * moved the RGBLED to shared library
    * added the find device api method
    * updated the save measurement api to simplify the data model
    * Added the data service shared library
    * Got the device registration process working
    * more updates
    * minor tweaks
    * Changed to node 22 for angular 19 support
    * updated data model for values for calculations
    * Updated API for devices to include the volume calculations
    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
    [Keg Weight Monitor - Bottom.stl, Keg Weight Monitor - Feet.stl, Keg Weight Monitor - Load Cell Mount Top Bevel.stl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]
2025-05-30 Fixed device creation
2025-07-03 Add auth to API/Web service (#2)
    * Added auth
    * added support for service accounts
    * fixed auth issues and added edit profile page
    * Added Users page
    * more fixes
    [config.h]
2025-07-07 Fixed error with device sending beaer token
    [config.h]
2025-07-07 fixed env.h build errors
    [config.h]
2025-07-07 added api key to devices list for admins
2025-07-08 added chip details to device list for admins
2025-07-08 fixed error when device is trying to update their status
2025-07-08 Added emptyKegWeightGrams to device API output
2025-07-08 added support for setting the empty keg weight on device
2025-07-17 updated angular material

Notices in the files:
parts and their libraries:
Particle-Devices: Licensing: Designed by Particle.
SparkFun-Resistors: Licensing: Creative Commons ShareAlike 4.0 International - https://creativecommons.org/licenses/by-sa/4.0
